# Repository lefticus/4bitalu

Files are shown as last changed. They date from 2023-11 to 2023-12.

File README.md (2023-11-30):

# 4bitalu

[digikey BOM](https://www.digikey.com/en/mylists/list/D8YFZJU3KQ)

## Background

This project is derived from my ECPE 2504 class that I took at Virginia Tech. The project was submitted on March 18, 1998.

The goal of the class project was to create a "Nibble Slice ALU".

This was a project that had:

 * A 4 bit register (SR Latch Flip-Flop)
 * 4 bit opcode input
 * 4 bit operand input

We were allowed to use 7400 series TTL logic chips

 * 74153 4-bit multiplexers (x2)
 * 74175 Flip-Flop
 * 7483 4-bit adder
 * 7400 Quad NAND (x3)

The projects were built on breadboards with jumpers, switches, chips provided by the university (no pictures of the original were taken)

Requirements:

* 'A' input is the 4bit flip-flop
* 'B' input is a 4bit dip switch
* OpCode is a 4bit dip switch
* 8 instructions were required
  1. A <- A (Hold)
  2. A <- shr A (Shift-Right A)
  3. A <- A+B (Add B to A)
  4. A <- A+B+1 (Add B to A + 1)
  5. A <- A+1 (Increment A)
  6. A <- A' (Complement A)
  7. A <- 0 (Clear A)
  8. A <- A' OR B (Imply)

8 instructions were required - but we have 16 possible opcodes. That means we ended up with an additional 8 "unintended" or "undocumented" OpCodes!

The original product requirements doc follows:
 
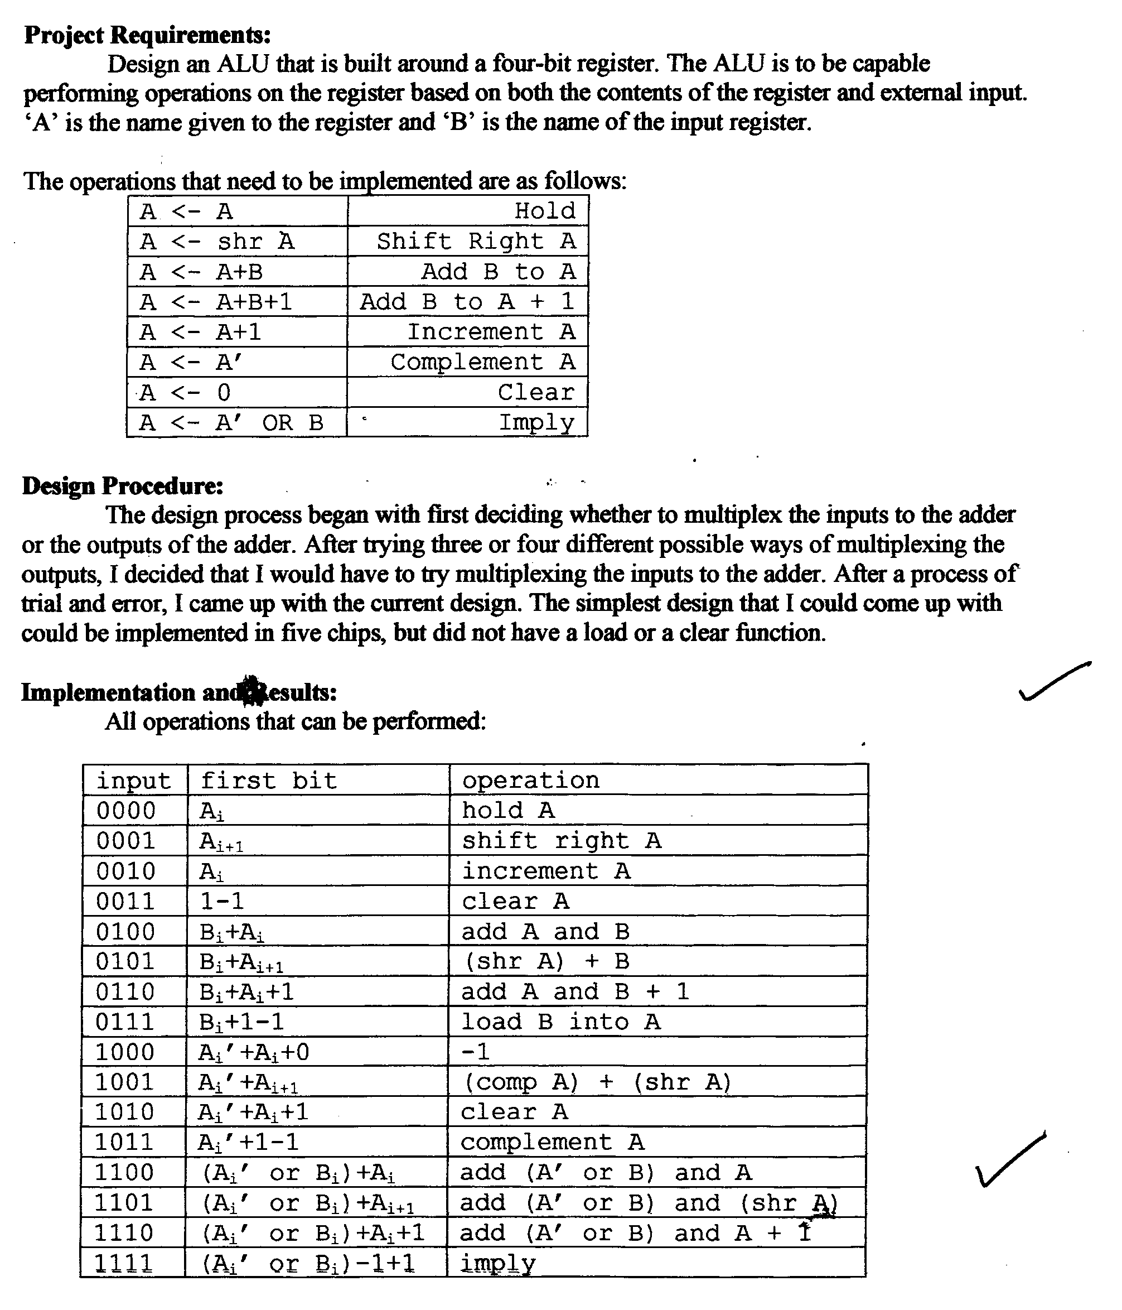
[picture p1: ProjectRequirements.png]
Original Requirements Doc

  
## Original Design

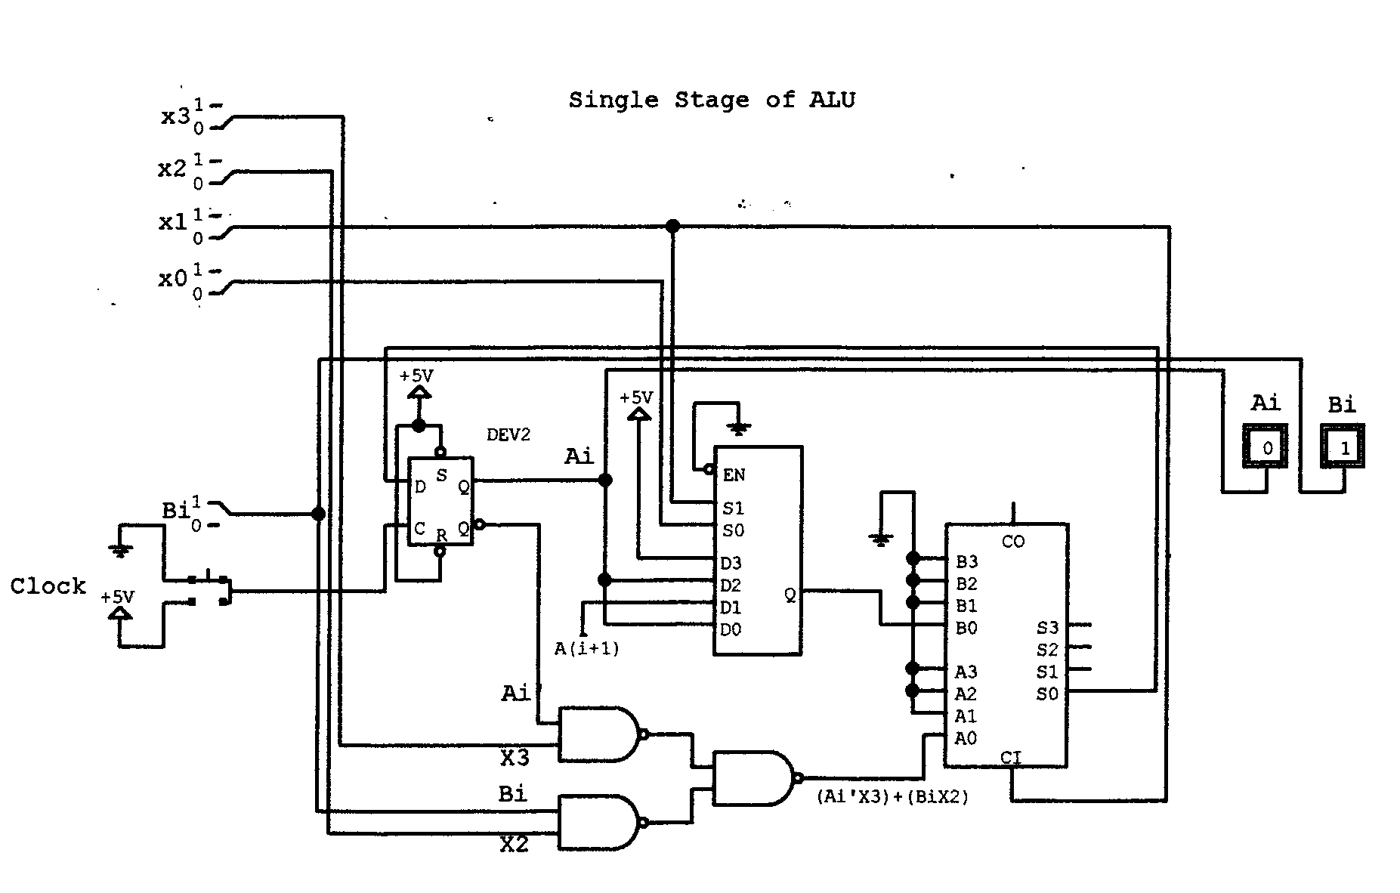
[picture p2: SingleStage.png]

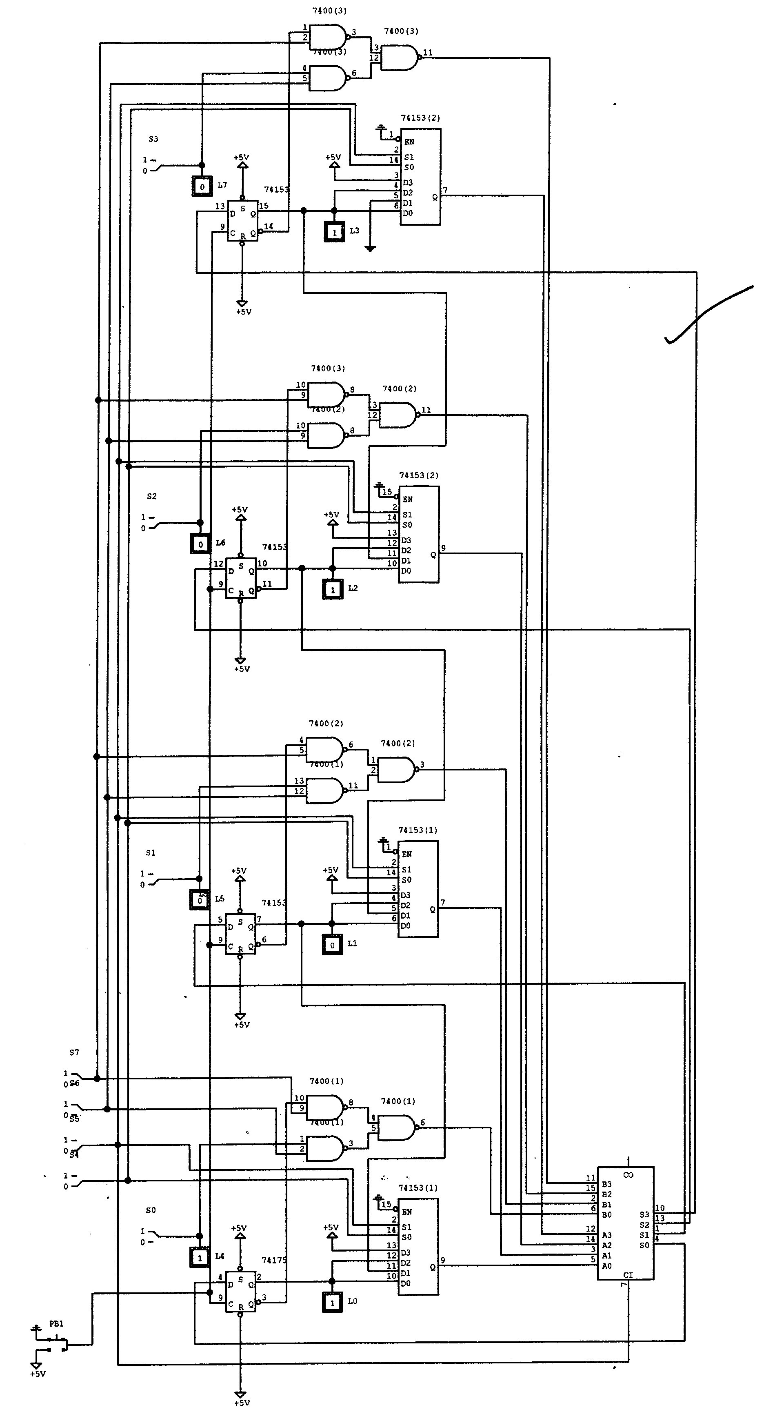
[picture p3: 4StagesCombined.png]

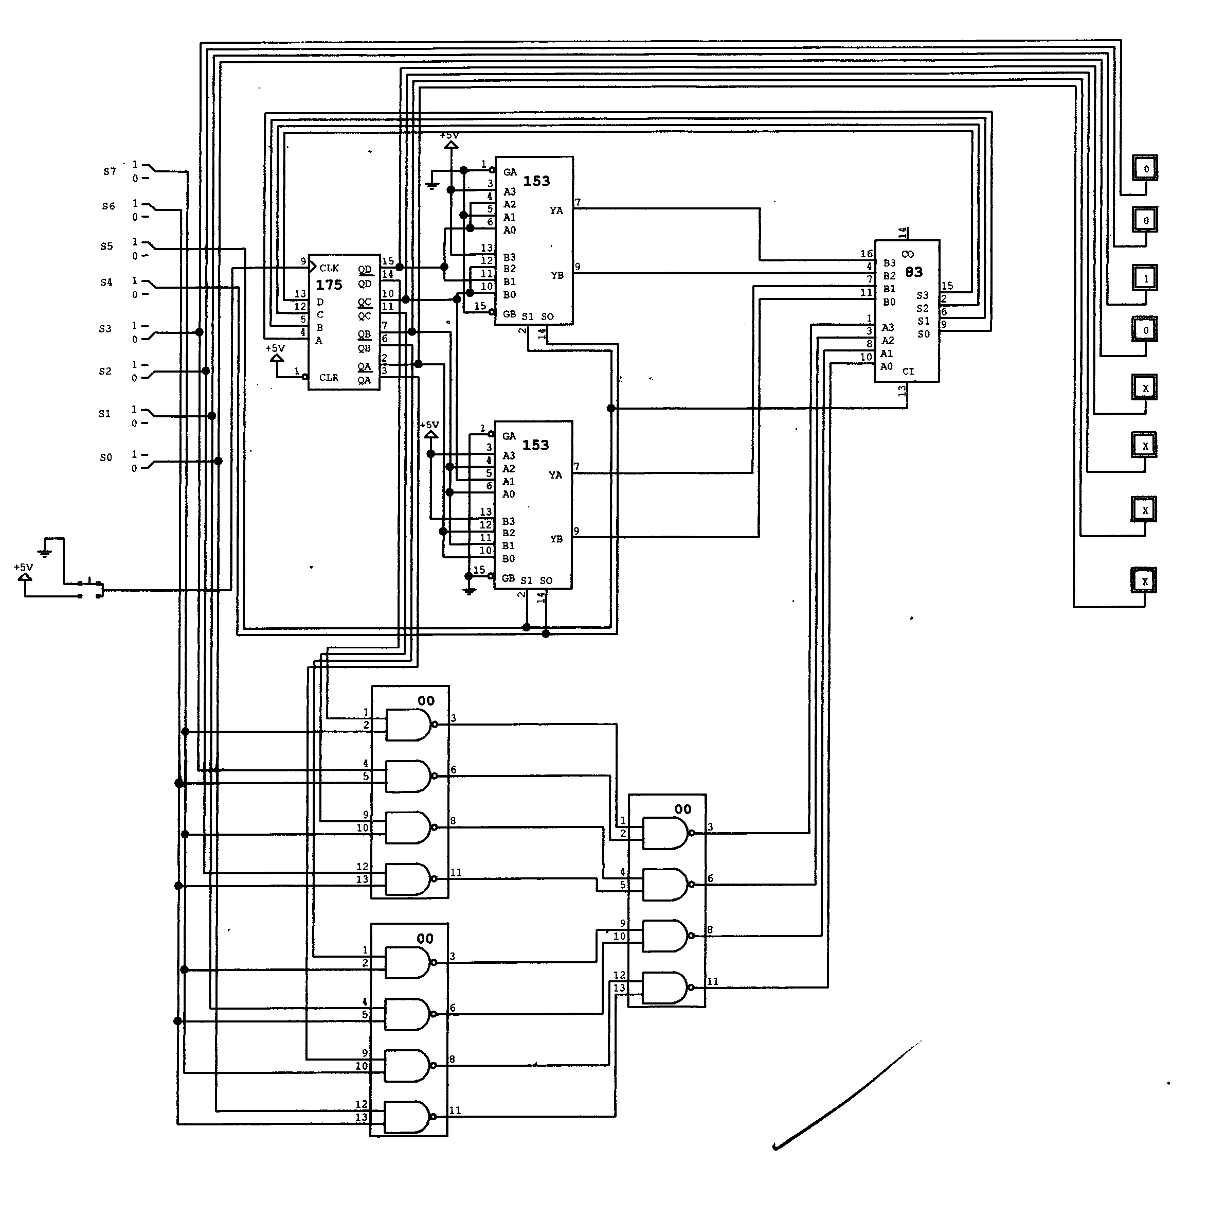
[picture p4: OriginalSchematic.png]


## 2023 Build

I decided 25 years later to try my hand at PCB design and to actually build this old project. This took 2 revisions:

1. [Rev 1](df868067a174cf4c2a293e076a1fb69d7d88c638) had several issues
  * Power pins were not connected
  * Clock signal was not connected
  * All of the bits input to the adder were reversed because the new tool I was using (KiCad) had the pins in a different order compared to the schematics from 1998
  * The register LEDs were actually connected to the output of the adder, not to the output of the Flip-Flop (so I was reading what would be, not what currently was!)
2. [Rev 2](fc047236eafd9e9970c500b91abf409b33e64aa5) fixed those problems, and did not introduce any new ones, it does work!
  * Except that the pull-down resistors for the inputs are spec'd too high, so the carry-in bit to the adder was always around 1 volt.
  * This should not have been a problem, those adders should not register high unless the value is at least 2v, but it was always Carrying-In an extra bit (effectively every result was the expected result + 1)
  * Also many (optional) LEDs are added for observing the processes in play
3. Rev 3 is currently in process
  * Adds power filtering capacitors to the VCC of the 74's chips
  * Inverts the output of the clock switch (in rev2 down is high and up is low)
  * Adds an LED to show the current state of the clock input

These project files are all in KiCad format, if anyone wishes to fork / build their own / test this stuff out too

## Images

## Rev 1

Rev 1 Empty

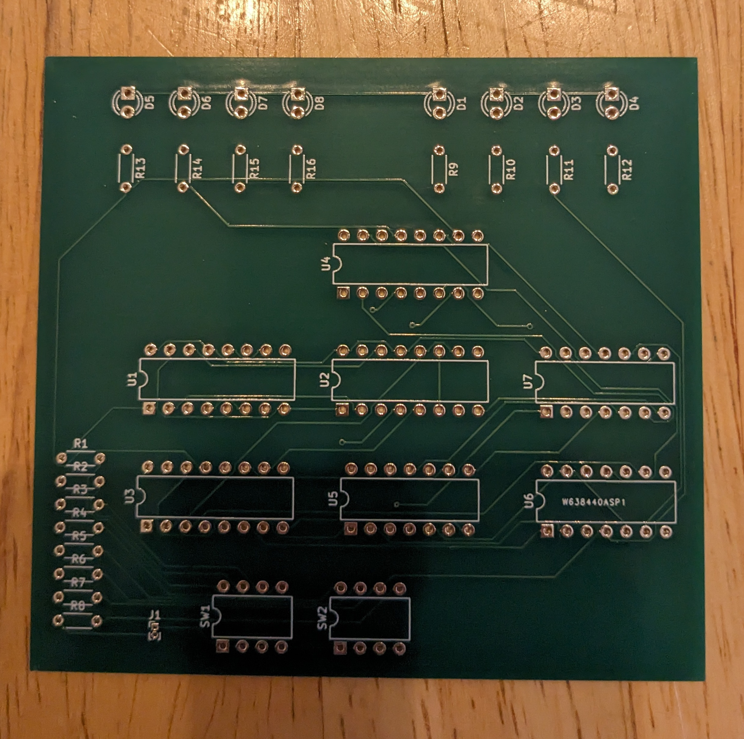
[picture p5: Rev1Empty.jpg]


Rev 1 Front

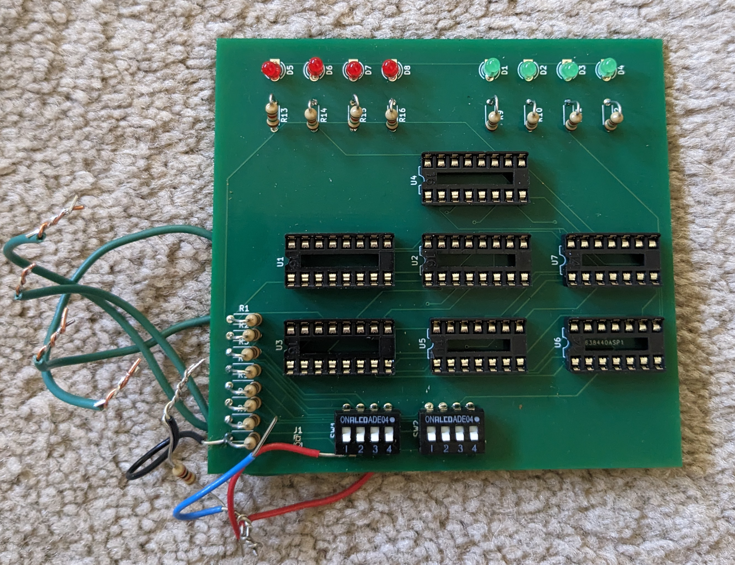
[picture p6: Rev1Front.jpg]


Rev 1 Back with bodge wires

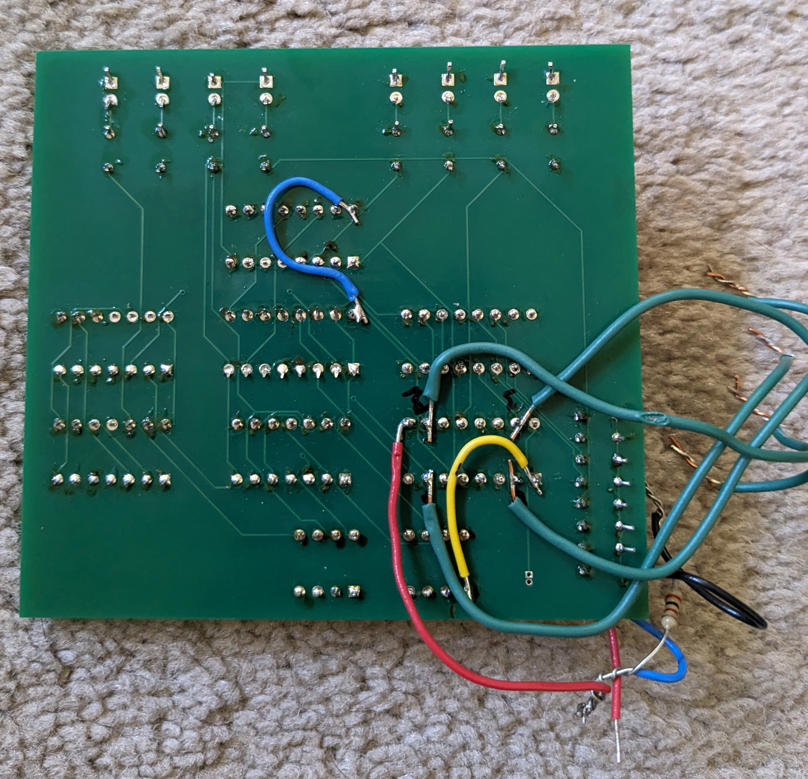
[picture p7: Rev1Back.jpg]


## Rev 2

Rev 2 Empty

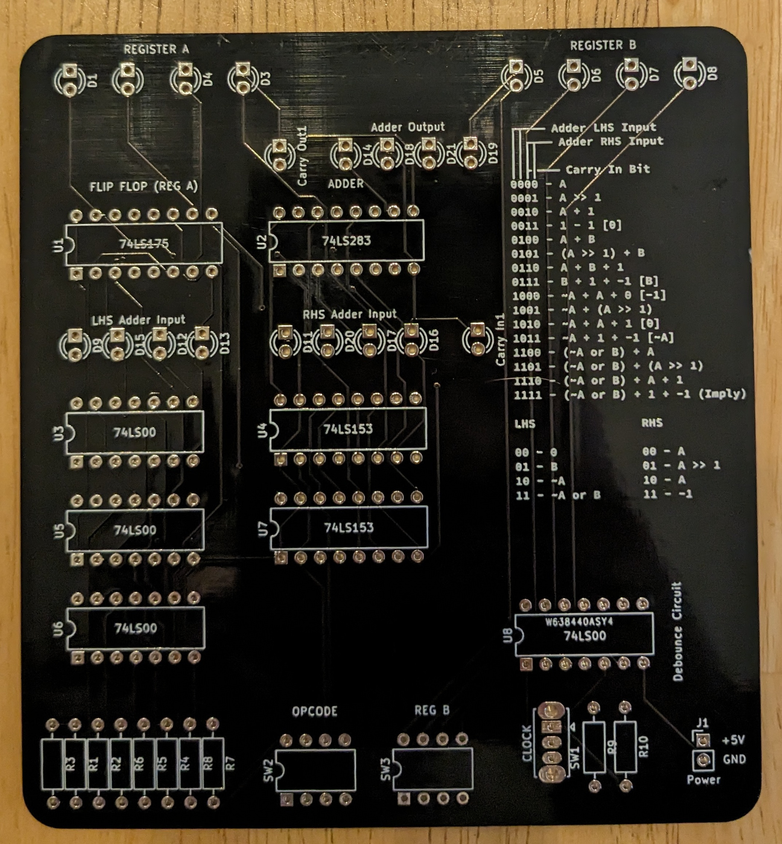
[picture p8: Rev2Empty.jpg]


Rev 2 Running!

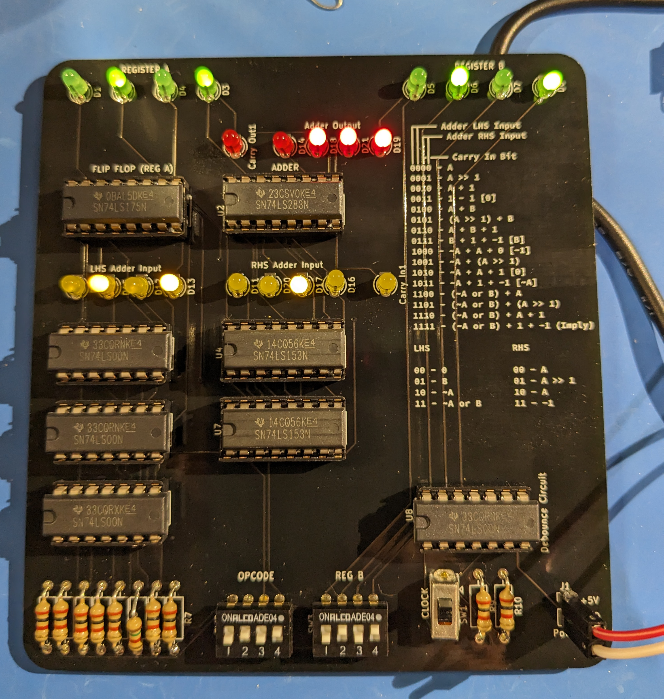
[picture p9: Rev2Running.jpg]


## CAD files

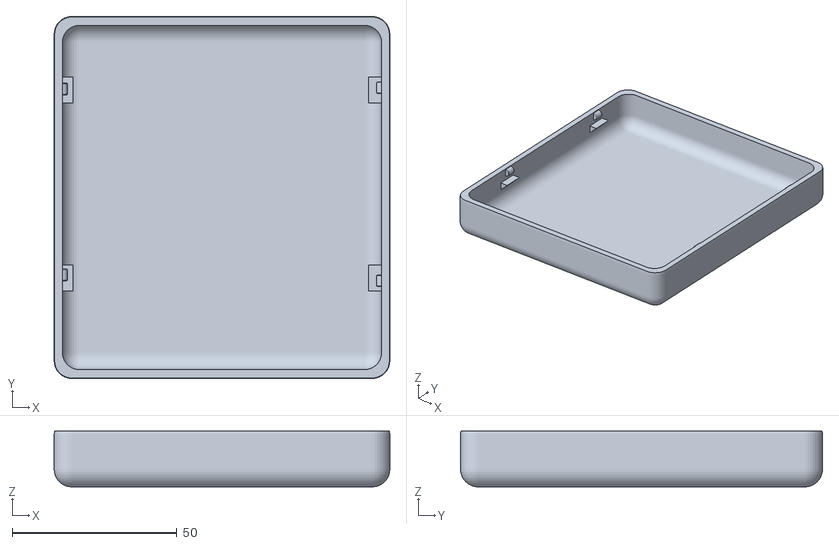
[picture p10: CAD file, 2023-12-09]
4bitalu case.stl
101.8 x 109.8 x 16.9

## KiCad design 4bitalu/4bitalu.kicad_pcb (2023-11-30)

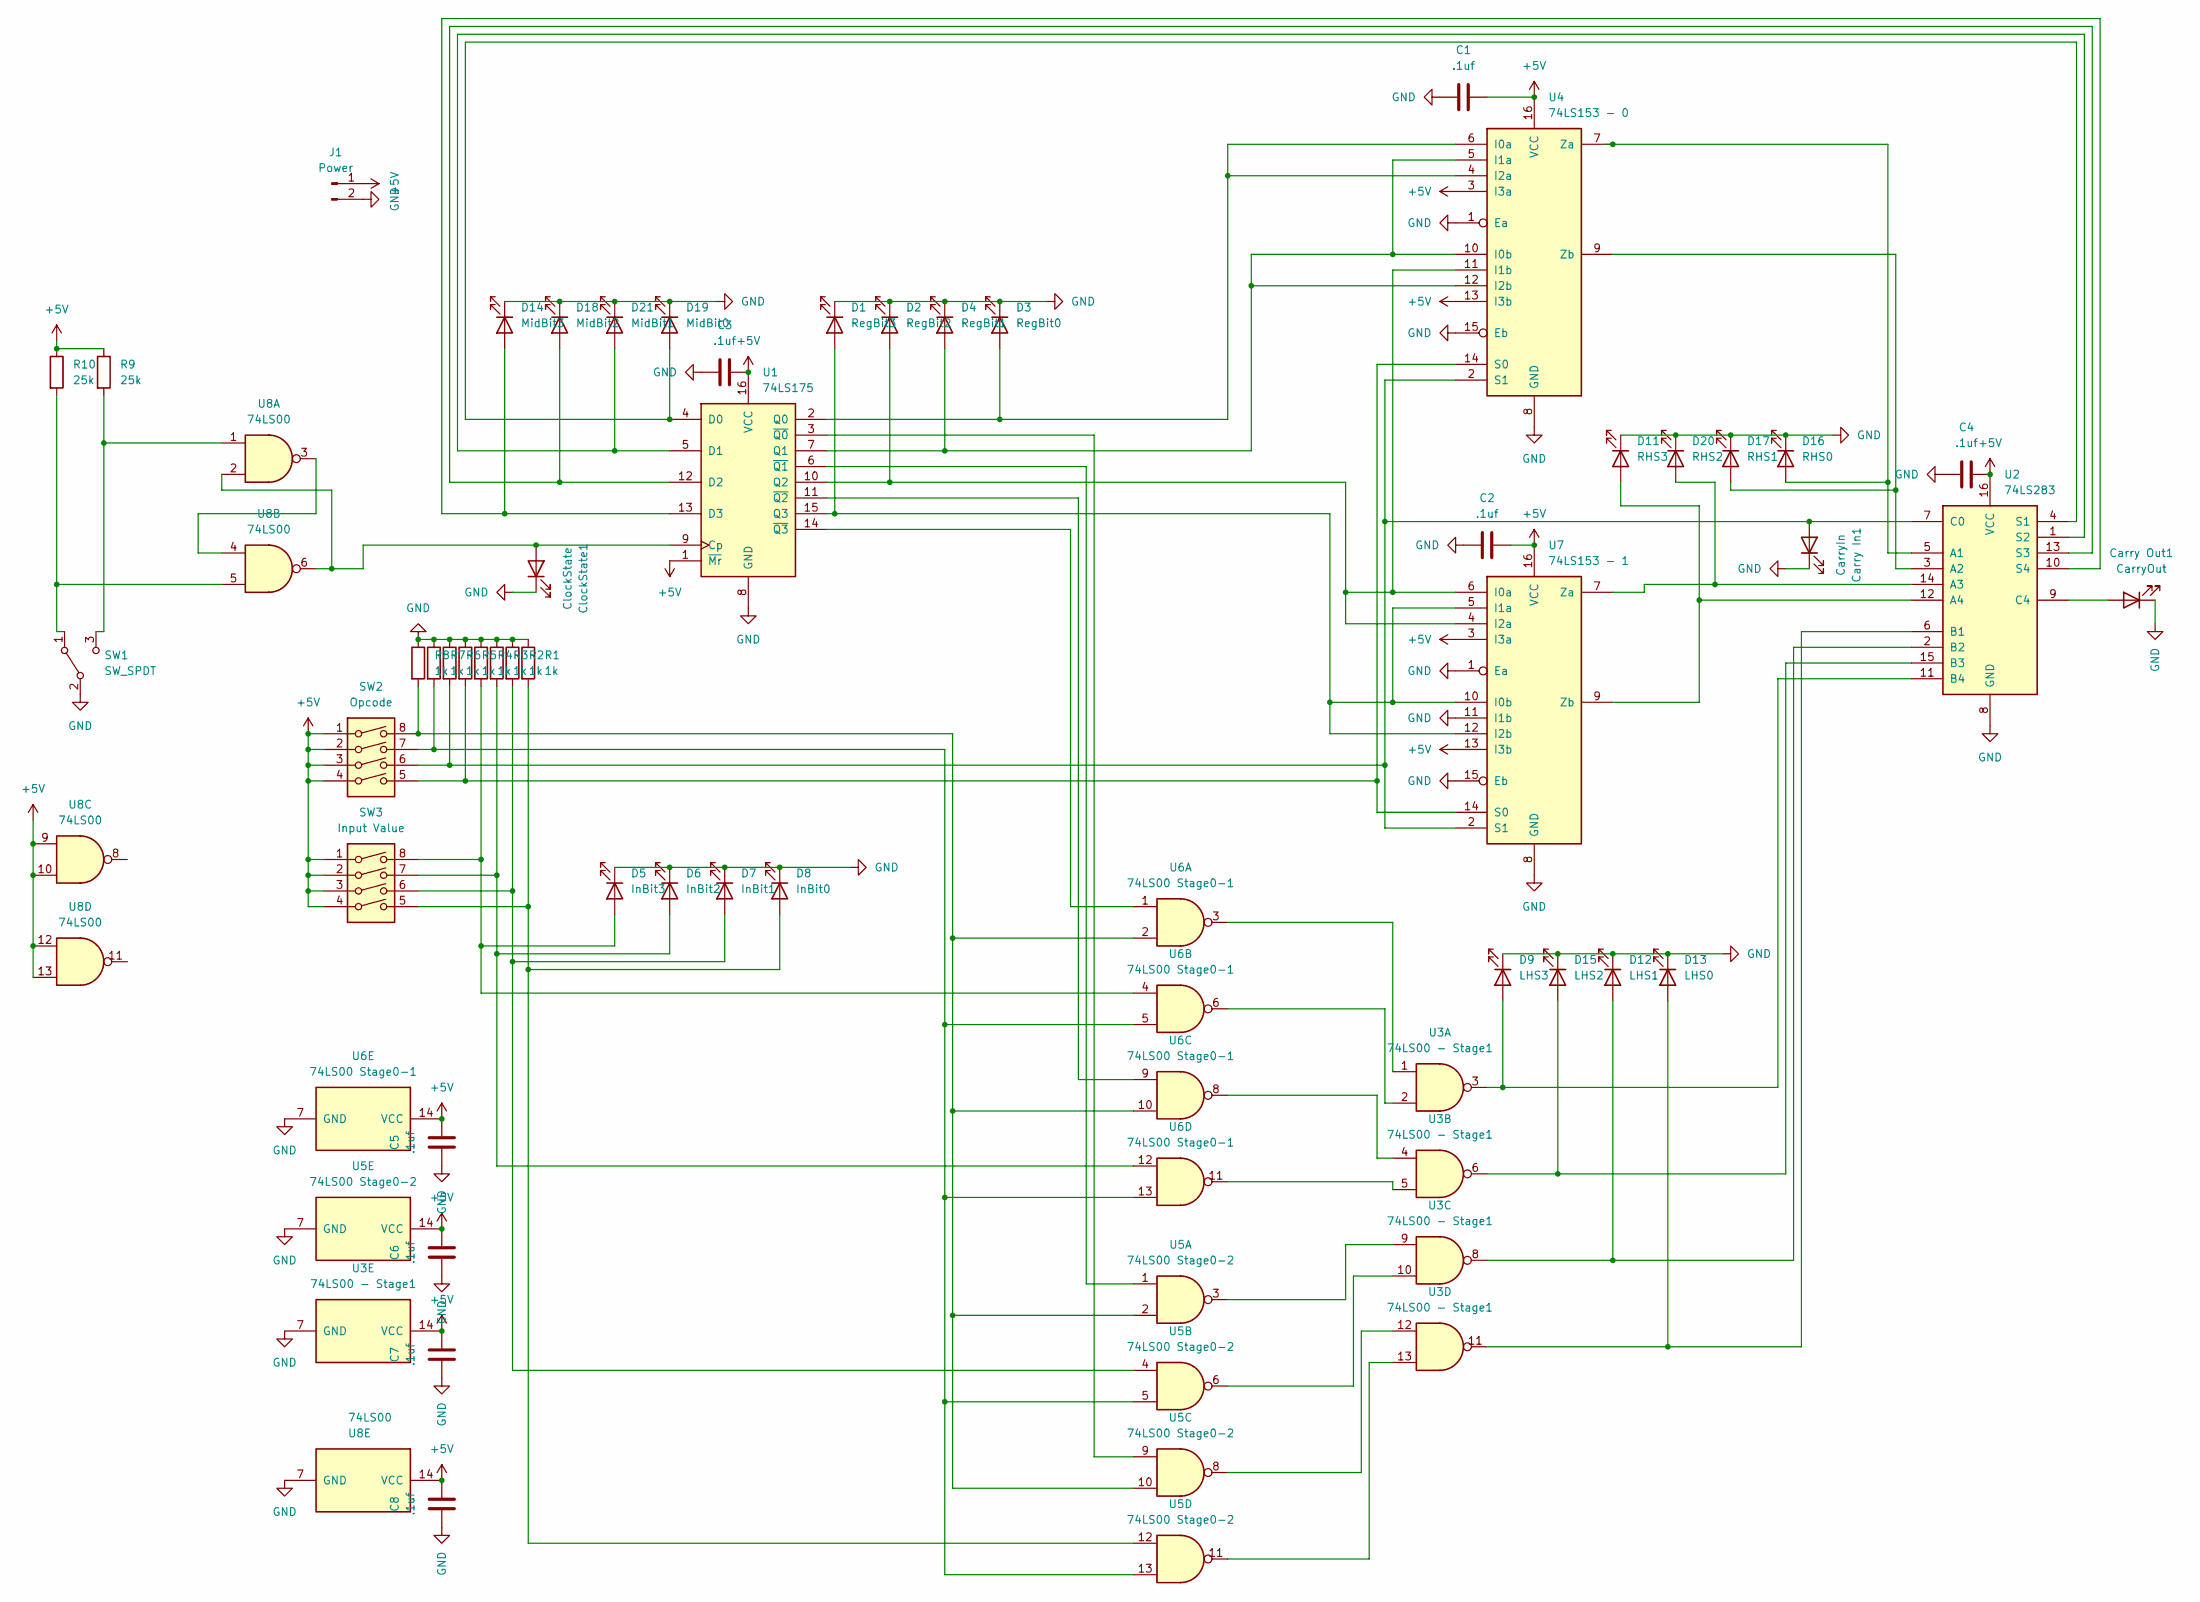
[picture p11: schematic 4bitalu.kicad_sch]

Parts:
C1, C2, C3, C4, C5, C6, C7, C8: .1uf; C_Disc_D3.0mm_W1.6mm_P2.50mm
Carry In1: CarryIn; LED_D3.0mm
Carry Out1: CarryOut; LED_D3.0mm
ClockState1: ClockState; LED_D3.0mm
D1: RegBit3; LED_D3.0mm
D2: RegBit2; LED_D3.0mm
D3: RegBit0; LED_D3.0mm
D4: RegBit1; LED_D3.0mm
D5: InBit3; LED_D3.0mm
D6: InBit2; LED_D3.0mm
D7: InBit1; LED_D3.0mm
D8: InBit0; LED_D3.0mm
D9: LHS3; LED_D3.0mm
D11: RHS3; LED_D3.0mm
D12: LHS1; LED_D3.0mm
D13: LHS0; LED_D3.0mm
D14: MidBit3; LED_D3.0mm
D15: LHS2; LED_D3.0mm
D16: RHS0; LED_D3.0mm
D17: RHS1; LED_D3.0mm
D18: MidBit2; LED_D3.0mm
D19: MidBit0; LED_D3.0mm
D20: RHS2; LED_D3.0mm
D21: MidBit1; LED_D3.0mm
J1: Power; PinHeader_1x02_P2.54mm_Vertical
R1, R2, R3, R4, R5, R6, R7, R8: 1k; R_Axial_DIN0207_L6.3mm_D2.5mm_P10.16mm_Horizontal
R9, R10: 25k; R_Axial_DIN0207_L6.3mm_D2.5mm_P10.16mm_Horizontal
SW1: SW_SPDT; SW_Slide_1P2T_CK_OS102011MS2Q
SW2: Opcode; DIP-8_W7.62mm
SW3: Input Value; DIP-8_W7.62mm
U1: 74LS175; DIP-16_W7.62mm
U2: 74LS283; DIP-16_W7.62mm
U3: 74LS00 - Stage1; DIP-14_W7.62mm
U4: 74LS153 - 0; DIP-16_W7.62mm
U5: 74LS00 Stage0-2; DIP-14_W7.62mm
U6: 74LS00 Stage0-1; DIP-14_W7.62mm
U7: 74LS153 - 1; DIP-16_W7.62mm
U8: 74LS00; DIP-14_W7.62mm

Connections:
+5V: C1.1, C2.1, C3.1, C4.1, C5.1, C6.1, C7.1, C8.1, J1.1, R9.1, R10.1, SW2.1, SW2.2, SW2.3, SW2.4, SW3.1, SW3.2, SW3.3, SW3.4, U1.1 (~Mr), U1.16 (VCC), U2.16 (VCC), U3.14 (VCC), U4.3 (I3a), U4.13 (I3b), U4.16 (VCC), U5.14 (VCC), U6.14 (VCC), U7.3 (I3a), U7.13 (I3b), U7.16 (VCC), U8.9, U8.10, U8.12, U8.13, U8.14 (VCC)
GND: C1.2, C2.2, C3.2, C4.2, C5.2, C6.2, C7.2, C8.2, Carry In1.1 (K), Carry Out1.1 (K), ClockState1.1 (K), D1.1 (K), D2.1 (K), D3.1 (K), D4.1 (K), D5.1 (K), D6.1 (K), D7.1 (K), D8.1 (K), D9.1 (K), D11.1 (K), D12.1 (K), D13.1 (K), D14.1 (K), D15.1 (K), D16.1 (K), D17.1 (K), D18.1 (K), D19.1 (K), D20.1 (K), D21.1 (K), J1.2, R1.1, R2.1, R3.1, R4.1, R5.1, R6.1, R7.1, R8.1, SW1.2 (B), U1.8 (GND), U2.8 (GND), U3.7 (GND), U4.1 (Ea), U4.8 (GND), U4.15 (Eb), U5.7 (GND), U6.7 (GND), U7.1 (Ea), U7.8 (GND), U7.11 (I1b), U7.15 (Eb), U8.7 (GND)
unnamed: Carry In1.2 (A), R6.2, SW2.6, U2.7 (C0), U4.2 (S1), U7.2 (S1)
unnamed: Carry Out1.2 (A), U2.9 (C4)
unnamed: ClockState1.2 (A), U1.9 (Cp), U8.2, U8.6
unnamed: D1.2 (A), U1.15 (Q3), U7.5 (I1a), U7.10 (I0b), U7.12 (I2b)
unnamed: D2.2 (A), U1.10 (Q2), U4.11 (I1b), U7.4 (I2a), U7.6 (I0a)
unnamed: D3.2 (A), U1.2 (Q0), U4.4 (I2a), U4.6 (I0a)
unnamed: D4.2 (A), U1.7 (Q1), U4.5 (I1a), U4.10 (I0b), U4.12 (I2b)
unnamed: D5.2 (A), R4.2, SW3.8, U6.4
unnamed: D6.2 (A), R3.2, SW3.7, U6.12
unnamed: D7.2 (A), R2.2, SW3.6, U5.4
unnamed: D8.2 (A), R1.2, SW3.5, U5.12
unnamed: D9.2 (A), U2.11 (B4), U3.3
unnamed: D11.2 (A), U2.12 (A4), U7.9 (Zb)
unnamed: D12.2 (A), U2.2 (B2), U3.8
unnamed: D13.2 (A), U2.6 (B1), U3.11
unnamed: D14.2 (A), U1.13 (D3), U2.10 (S4)
unnamed: D15.2 (A), U2.15 (B3), U3.6
unnamed: D16.2 (A), U2.5 (A1), U4.7 (Za)
unnamed: D17.2 (A), U2.3 (A2), U4.9 (Zb)
unnamed: D18.2 (A), U1.12 (D2), U2.13 (S3)
unnamed: D19.2 (A), U1.4 (D0), U2.4 (S1)
unnamed: D20.2 (A), U2.14 (A3), U7.7 (Za)
unnamed: D21.2 (A), U1.5 (D1), U2.1 (S2)
unnamed: R7.2, SW2.7, U5.5, U5.13, U6.5, U6.13
unnamed: R8.2, SW2.8, U5.2, U5.10, U6.2, U6.10
unnamed: R10.2, SW1.1 (A), U8.5
unnamed: R9.2, SW1.3 (C), U8.1
unnamed: U1.3 (~Q0), U5.9
unnamed: U1.6 (~Q1), U5.1
unnamed: U1.11 (~Q2), U6.9
unnamed: U1.14 (~Q3), U6.1
unnamed: U3.1, U6.3
unnamed: U3.2, U6.6
unnamed: U3.4, U6.8
unnamed: U3.5, U6.11
unnamed: U3.9, U5.3
unnamed: U3.10, U5.6
unnamed: U3.12, U5.8
unnamed: U3.13, U5.11
unnamed: R5.2, SW2.5, U4.14 (S0), U7.14 (S0)
unnamed: U8.3, U8.4

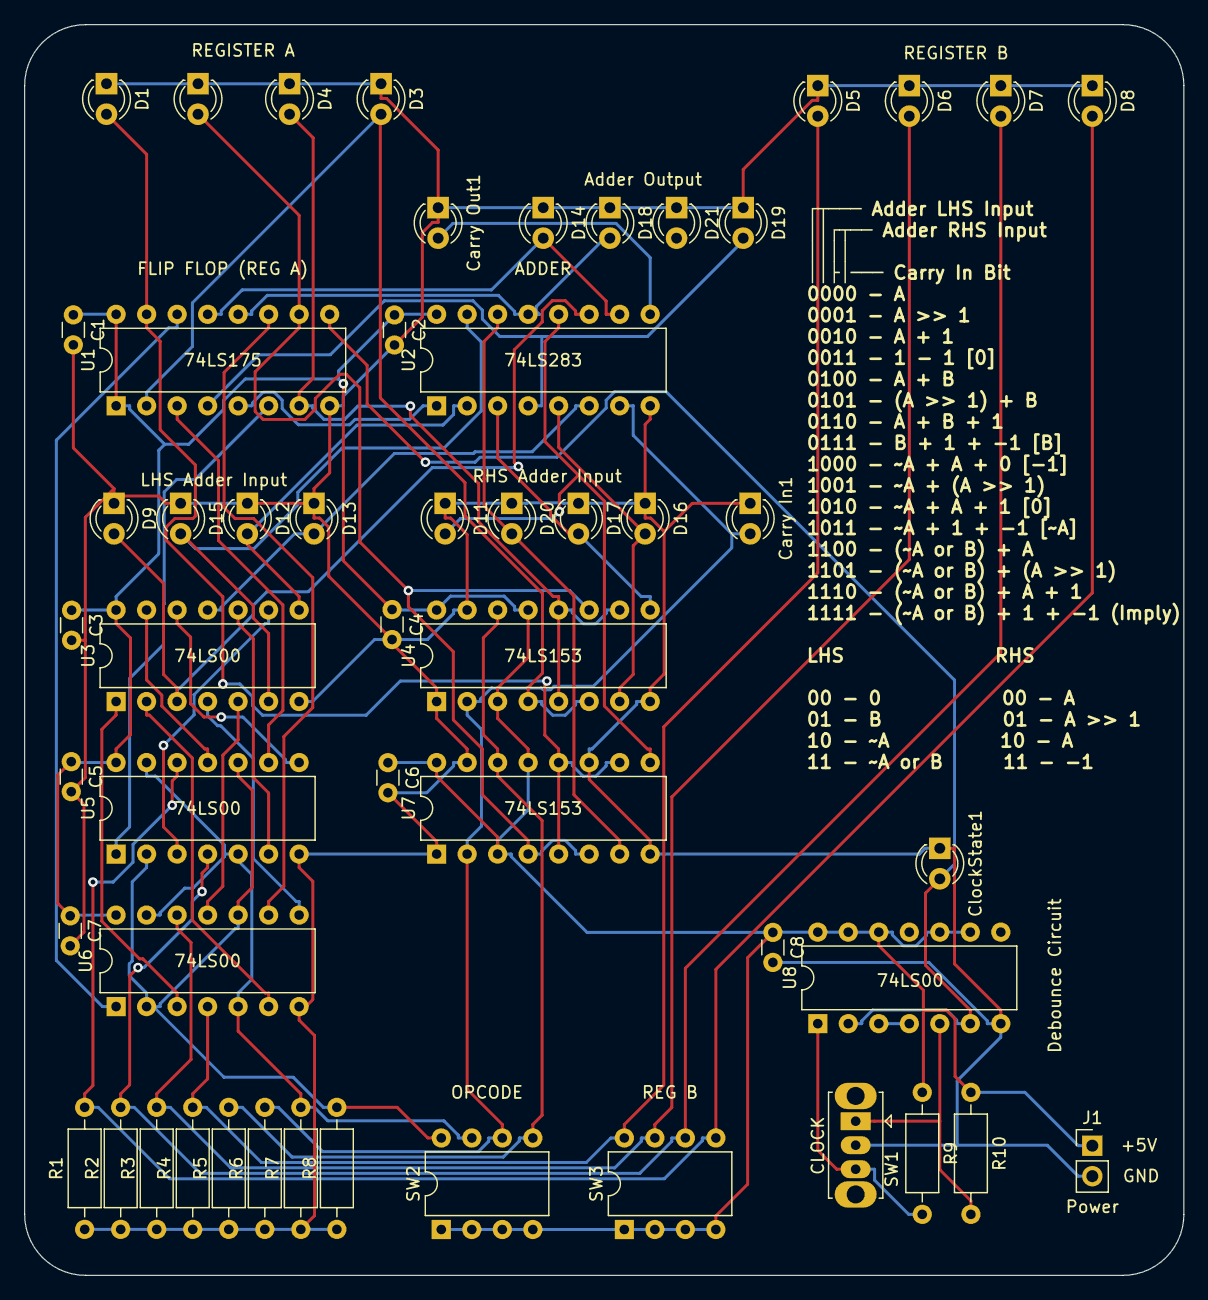
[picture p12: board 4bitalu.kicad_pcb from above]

Board: 2 copper layers, 96.5 x 104.1 mm, 53 parts (0 on the bottom side), 43 nets.

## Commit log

2023-11-30 Initial PCB generated
    [4bitalu.kicad_pcb, 4bitalu.kicad_sch]
2023-11-30 Rev 2 of PCB design
    Known issues:
    * Pulldown resistors are too high (should be 1k)
    * Missing capacitors for power inputs on chips
    * Inputs on unused NAND gates are not tied high
    * Clock switch is in unexepected orientation
    [4bitalu.kicad_pcb, 4bitalu.kicad_sch]
2023-11-30 Revision 3 mostly ready
    * Adds caps on power
    * Inverts logic for clock switch
    * Adds optional clock LED
    * Changes pulldown resistors to 1k
    Note: this design should also work with 3.3v logic and LEDs
    [4bitalu.kicad_pcb, 4bitalu.kicad_sch]
2023-11-30 Rename 4 Stages Combined.png to 4StagesCombined.png
2023-11-30 Add board images
2023-11-30 Add link to BOM for digikey
2023-12-09 Initial take on a 3d printable design for the case
    [4bitalu case.stl]
